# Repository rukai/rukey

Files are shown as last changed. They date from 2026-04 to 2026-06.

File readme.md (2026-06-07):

# Rukey



## About

This was designed quickly as my personal keyboard, I would like to make this a properly documented project that others can build but don't have the capacity at the moment.

I used the sofle pico as a base but changed pretty much everything in order to recreate the moonlander but with the goal of being a budget build.

## BOM

[Printed parts onshape](https://cad.onshape.com/documents/f6585266405bfc96ac0755a6/w/eb9972e583e4bd12c4cf19cb/e/e24845aae63ec51d7ef00fa9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)

|Quantity|Item|Note|
|-|-|-|
|74| MX compatible switches| |
|74| MX compatible kailh hotswap sockets| |
|74| Surface mount SOD-123 1N4148 diodes| |
|2| 2x08 2.00mm IDC straight socket| |
|1| 2x08 2.00mm IDC cable - at least 20cm long| |
|4| 2x03 2.00mm pin header |used as IDC socket in tight area |
|2| 2x03 2.00mm IDC cable - ~10cm long | |
|1| printed left base|print with supports for the bridge, can be done with auto supports configured to 1 degree|
|1| printed right base| same as above|
|1| printed switch plate - left main|no supports|
|1| printed switch plate - right main|no supports|
|1| printed switch plate - left thumb cluster|no supports|
|1| printed switch plate - right thumb cluster|no supports|
|2| printed washers|no supports|
|4| m3 machine screws - 25mm long||
|2| m3 machine screws - 20mm long||
|2| m3 machine screws - 14mm long||
|2| m3 machine screws - 12mm long||
|10| m3 square nuts| |
|2|main PCB| |
|2|thumb cluster PCB| |

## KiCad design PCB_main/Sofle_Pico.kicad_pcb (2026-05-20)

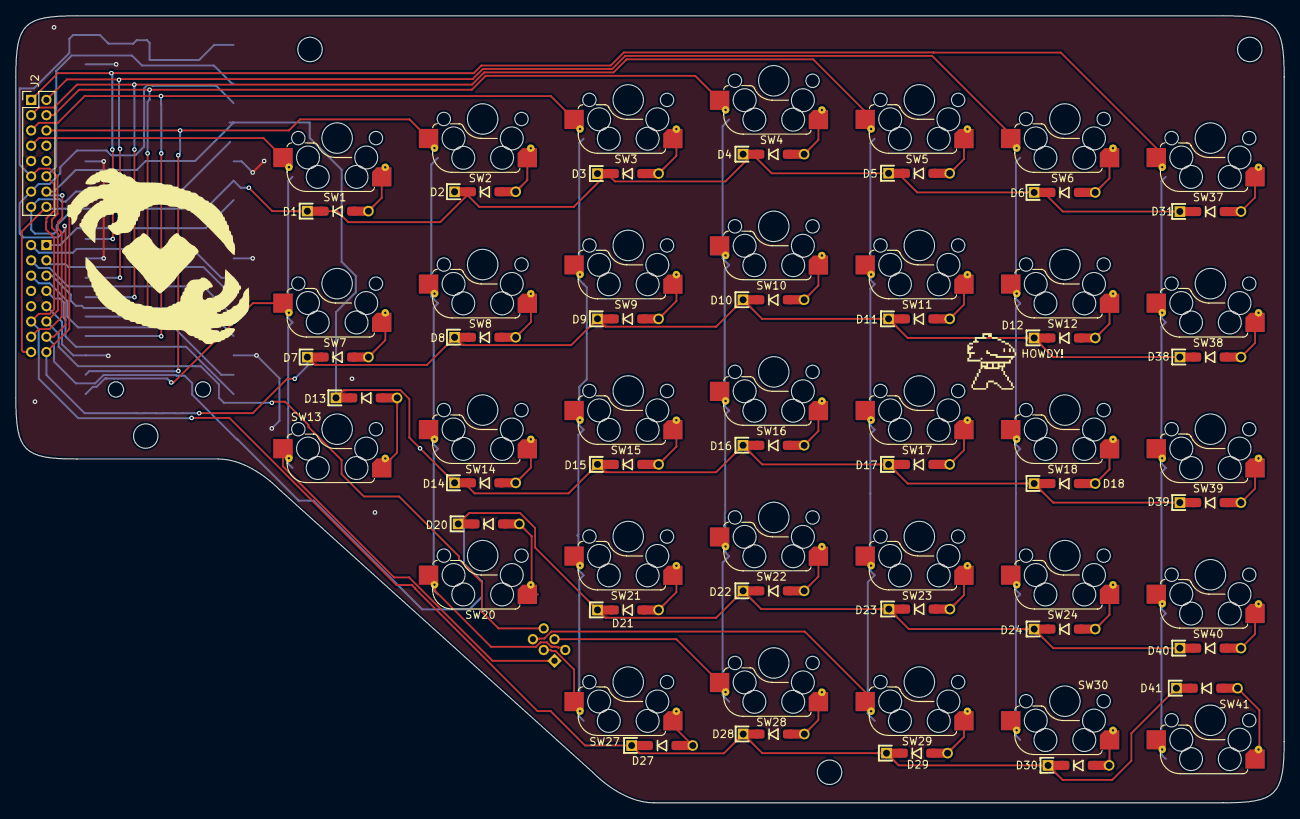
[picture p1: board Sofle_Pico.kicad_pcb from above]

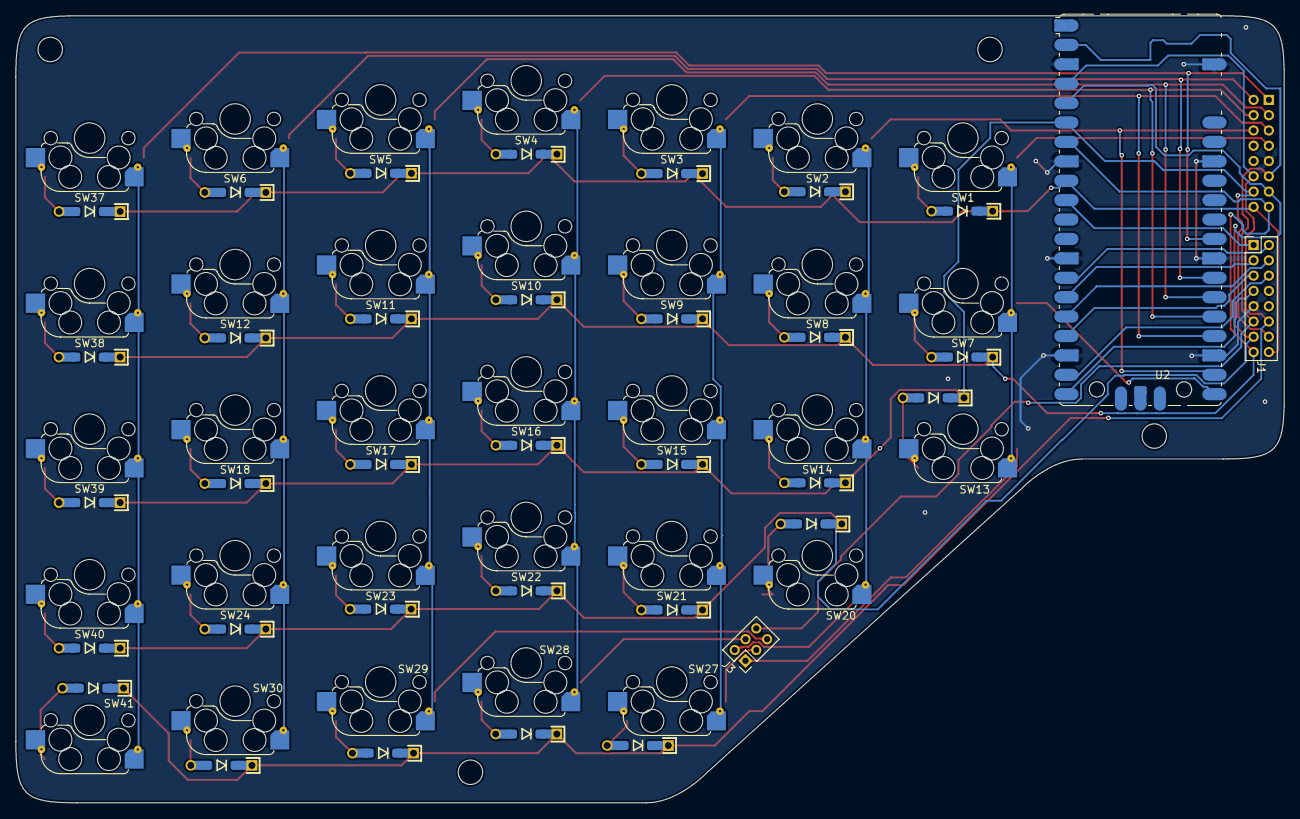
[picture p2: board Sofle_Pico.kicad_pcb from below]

Board: 2 copper layers, 166.0 x 103.0 mm, 68 parts (67 on the bottom side), 53 nets.

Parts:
D1, D2, D3, D4, D5, D6, D7, D8, D9, D10, D11, D12, D13, D14, D15, D16, D17, D18, D20, D21, D22, D23, D24, D27, D28, D29, D30, D31, D38, D39, D40, D41: D; D_SOD-123_DO-35_Hybrid_DoubleSided_V2
J1, J2: Conn_02x08_Top_Bottom; PinHeader_2x08_P2.00mm_Vertical
J3: Conn_02x03; PinHeader_2x03_P2.00mm_Vertical
SW1, SW2, SW3, SW4, SW5, SW6, SW7, SW8, SW9, SW10, SW11, SW12, SW13, SW14, SW15, SW16, SW17, SW18, SW20, SW21, SW22, SW23, SW24, SW27, SW28, SW29, SW30, SW37, SW38, SW39, SW40, SW41: SW_PUSH; Cherry_MX_DS_Hotswap_v3.5.4
U2: Pico; RaspberryPi_Pico_SMD

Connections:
GND: J1.9, J2.9, U2.3 (GND), U2.8 (GND), U2.13 (GND), U2.18 (GND), U2.23 (GND), U2.28 (GND), U2.33 (AGND), U2.38 (GND)
unnamed: D1.2 (A), SW1.2
unnamed: D2.2 (A), SW2.2
unnamed: D3.2 (A), SW3.2
unnamed: D4.2 (A), SW4.2
unnamed: D5.2 (A), SW5.2
unnamed: D6.2 (A), SW6.2
unnamed: D7.2 (A), SW7.2
unnamed: D8.2 (A), SW8.2
unnamed: D9.2 (A), SW9.2
unnamed: D10.2 (A), SW10.2
unnamed: D11.2 (A), SW11.2
unnamed: D12.2 (A), SW12.2
unnamed: D13.2 (A), SW13.2
unnamed: D14.2 (A), SW14.2
unnamed: D15.2 (A), SW15.2
unnamed: D16.2 (A), SW16.2
unnamed: D17.2 (A), SW17.2
unnamed: D18.2 (A), SW18.2
unnamed: D20.2 (A), SW20.2
unnamed: D21.2 (A), SW21.2
unnamed: D22.2 (A), SW22.2
unnamed: D23.2 (A), SW23.2
unnamed: D24.2 (A), SW24.2
unnamed: D27.2 (A), SW27.2
unnamed: D28.2 (A), SW28.2
unnamed: D29.2 (A), SW29.2
unnamed: D30.2 (A), SW30.2
unnamed: D31.2 (A), SW37.2
unnamed: D38.2 (A), SW38.2
unnamed: D39.2 (A), SW39.2
unnamed: D40.2 (A), SW40.2
unnamed: D41.2 (A), SW41.2
lcol0: J2.7, J3.1, SW1.1, SW7.1, SW13.1, U2.21 (GPIO16)
lcol1: J2.6, J3.2, SW2.1, SW8.1, SW14.1, SW20.1, U2.22 (GPIO17)
lcol2: J2.5, J3.3, SW3.1, SW9.1, SW15.1, SW21.1, SW27.1, U2.24 (GPIO18)
lcol3: J2.4, J3.4, SW4.1, SW10.1, SW16.1, SW22.1, SW28.1, U2.25 (GPIO19)
lcol4: J2.3, J3.5, SW5.1, SW11.1, SW17.1, SW23.1, SW29.1, U2.26 (GPIO20)
lcol5: J2.2, SW6.1, SW12.1, SW18.1, SW24.1, SW30.1, U2.27 (GPIO21)
lcol6: J2.1, SW37.1, SW38.1, SW39.1, SW40.1, SW41.1, U2.29 (GPIO22)
rcol0: J1.7, U2.20 (GPIO15)
rcol1: J1.6, U2.19 (GPIO14)
rcol2: J1.5, U2.17 (GPIO13)
rcol3: J1.4, U2.16 (GPIO12)
rcol4: J1.3, U2.15 (GPIO11)
rcol5: J1.2, U2.14 (GPIO10)
rcol6: J1.1, U2.10 (GPIO7)
row0: D1.1 (K), D2.1 (K), D3.1 (K), D4.1 (K), D5.1 (K), D6.1 (K), D31.1 (K), J1.16, J2.16, U2.9 (GPIO6)
row1: D7.1 (K), D8.1 (K), D9.1 (K), D10.1 (K), D11.1 (K), D12.1 (K), D38.1 (K), J1.15, J2.15, U2.7 (GPIO5)
row2: D13.1 (K), D14.1 (K), D15.1 (K), D16.1 (K), D17.1 (K), D18.1 (K), D39.1 (K), J1.14, J2.14, U2.6 (GPIO4)
row3: D20.1 (K), D21.1 (K), D22.1 (K), D23.1 (K), D24.1 (K), D40.1 (K), J1.13, J2.13, U2.5 (GPIO3)
row4: D27.1 (K), D28.1 (K), D29.1 (K), D30.1 (K), D41.1 (K), J1.12, J2.12, U2.4 (GPIO2)
row5: J1.11, J2.11, J3.6, U2.2 (GPIO1)

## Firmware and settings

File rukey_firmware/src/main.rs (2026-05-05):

#![no_main]
#![no_std]

//! Stack usage.
//! The rukey firmware does not use an allocator.
//! Maybe it should, but its interesting to try writing software without an allocator,
//! and assuming we are well under the memory limit, using static buffers should make OoM issues impossible.
//!
//! However, currently rukey stores huge values on the stack, which is problematic because:
//! * The RP2040 only has 256KB of RAM
//! * embassy/async exacerbates stack usage issues
//!
//! memory.x is setup to assert that the linker has allocated at least 64KB of stack.
//! Currently, the firmware works fine, but long term we should move anything >= 1024 bytes off of the stack to avoid stack overflow issues.

mod config;
mod input;
mod keyboard;
mod mapping_state;
mod mouse;
mod usb;
mod web_config;

use crate::config::ConfigFlash;
use crate::input::Inputs;
use crate::keyboard::Keyboard;
use crate::mouse::Mouse;
use crate::web_config::WebConfig;
use embassy_executor::Spawner;

use {defmt_rtt as _, panic_probe as _};

#[embassy_executor::main]
async fn main(_spawner: Spawner) {
    let p = embassy_rp::init(Default::default());

    let config_flash = ConfigFlash::new(p.FLASH, p.DMA_CH0).await;

    let mut builder = usb::usb_builder(p.USB, config_flash).await;

    let mut web_config = WebConfig::new(&mut builder, config_flash);

    let mut keyboard = Keyboard::new(&mut builder);
    let mut mouse = Mouse::new(&mut builder);

    let mut usb = builder.build();

    // Run the USB device.
    let usb_fut = usb.run();

    let mut inputs = Inputs::new(
        config_flash,
        [
            Some(p.PIN_0.into()),
            Some(p.PIN_1.into()),
            Some(p.PIN_2.into()),
            Some(p.PIN_3.into()),
            Some(p.PIN_4.into()),
            Some(p.PIN_5.into()),
            Some(p.PIN_6.into()),
            Some(p.PIN_7.into()),
            Some(p.PIN_8.into()),
            Some(p.PIN_9.into()),
            Some(p.PIN_10.into()),
            Some(p.PIN_11.into()),
            Some(p.PIN_12.into()),
            Some(p.PIN_13.into()),
            Some(p.PIN_14.into()),
            Some(p.PIN_15.into()),
            Some(p.PIN_16.into()),
            Some(p.PIN_17.into()),
            Some(p.PIN_18.into()),
            Some(p.PIN_19.into()),
            Some(p.PIN_20.into()),
            Some(p.PIN_21.into()),
            Some(p.PIN_22.into()),
            Some(p.PIN_23.into()),
            Some(p.PIN_24.into()),
            Some(p.PIN_25.into()),
            Some(p.PIN_26.into()),
            Some(p.PIN_27.into()),
            Some(p.PIN_28.into()),
            Some(p.PIN_29.into()),
        ],
    );

    embassy_futures::join::join5(
        usb_fut,
        inputs.process(),
        keyboard.process(),
        mouse.process(),
        web_config.process(),
    )
    .await;
}

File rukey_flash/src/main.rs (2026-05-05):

use crate::flash::WriteConfig;
use clap::Parser;
use miette::Result;

pub mod buffer_nor_flash;
pub mod cli;
pub mod config;
pub mod elf;
pub mod flash;

fn main() -> Result<()> {
    // TODO: use this once -Z bindeps stabilizes
    // let firmware_bytes = elf::elf_to_bin(include_bytes!(env!(
    //     "CARGO_BIN_FILE_rukey_FIRMWARE_rukey_firmware"
    // )))?;
    let firmware_bytes = elf::elf_to_bin(include_bytes!(env!("FIRMWARE_PATH")))?;

    let cli = cli::Args::parse();
    let config = if cli.erase_config {
        WriteConfig::Clear
    } else {
        WriteConfig::Config(Box::new(config::load(cli.path)?))
    };
    flash::flash_device(&firmware_bytes, config)?;

    println!("Succesfully flashed!");
    Ok(())
}

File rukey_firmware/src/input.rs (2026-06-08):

use crate::config::{CONFIG_UPDATED, ConfigFlash};
use crate::mapping_state::MappingState;
use core::ops::ControlFlow;
use defmt::info;
use embassy_rp::gpio::{AnyPin, Input, Output, Pin, Pull};
use embassy_rp::{Peri, PeripheralType};
use embassy_sync::{blocking_mutex::raw::CriticalSectionRawMutex, mutex::Mutex};
use embassy_time::Timer;
use heapless::Vec;
use rukey_config::{MAX_MAPPINGS, Profile, RukeyInput};
use static_cell::StaticCell;

static CURRENT_PROFILE: StaticCell<Profile> = StaticCell::new();

pub struct Inputs {
    pins: [Option<Peri<'static, AnyPin>>; 30],
    config_flash: &'static Mutex<CriticalSectionRawMutex, ConfigFlash>,
}

impl Inputs {
    pub fn new(
        config_flash: &'static Mutex<CriticalSectionRawMutex, ConfigFlash>,
        pins: [Option<Peri<'static, AnyPin>>; 30],
    ) -> Self {
        Inputs { pins, config_flash }
    }

    pub async fn process(&mut self) {
        let mut rx = CONFIG_UPDATED.receiver().unwrap();

        // lcol pins 0-6
        // lcol pins are mirrored from rcol pins, so the two innermost columns are 0 and the outermost columns are 6.
        // However, to make mapping configuration feel more natural, we convert these mirrored pins into a series of columns from 0-13 going from left to right
        // i.e. 6543210 0123456
        let col0_pin = 22; // lcol 6
        let col1_pin = 21; // lcol 5
        let col2_pin = 20; // lcol 4
        let col3_pin = 19; // lcol 3
        let col4_pin = 18; // lcol 2
        let col5_pin = 17; // lcol 1
        let col6_pin = 16; // lcol 0

        // rcol pins 0-6
        let col7_pin = 15; // rcol 0
        let col8_pin = 14; // rcol 1
        let col9_pin = 13; // rcol 2
        let col10_pin = 12; // rcol 3
        let col11_pin = 11; // rcol 4
        let col12_pin = 10; // rcol 5
        let col13_pin = 7; // rcol 6

        let row0_pin = 6;
        let row1_pin = 5;
        let row2_pin = 4;
        let row3_pin = 3;
        let row4_pin = 2;
        let row5_pin = 1;

        // Load initial config
        let _meta = self.config_flash.lock().await.load_meta().await; // TODO: pin remappings
        let current_profile = {
            // TODO: currently handles config with 0 profiles by loading the default profile which has mappings in it.
            //       this is unintuitive and should be changed.
            let profile = self.config_flash.lock().await.load_profile(0).await;
            CURRENT_PROFILE.init(profile)
        };

        let mut cols = [
            output(self.pins[col0_pin].take().unwrap()),
            output(self.pins[col1_pin].take().unwrap()),
            output(self.pins[col2_pin].take().unwrap()),
            output(self.pins[col3_pin].take().unwrap()),
            output(self.pins[col4_pin].take().unwrap()),
            output(self.pins[col5_pin].take().unwrap()),
            output(self.pins[col6_pin].take().unwrap()),
            output(self.pins[col7_pin].take().unwrap()),
            output(self.pins[col8_pin].take().unwrap()),
            output(self.pins[col9_pin].take().unwrap()),
            output(self.pins[col10_pin].take().unwrap()),
            output(self.pins[col11_pin].take().unwrap()),
            output(self.pins[col12_pin].take().unwrap()),
            output(self.pins[col13_pin].take().unwrap()),
        ];
        let rows = [
            input(self.pins[row0_pin].take().unwrap()),
            input(self.pins[row1_pin].take().unwrap()),
            input(self.pins[row2_pin].take().unwrap()),
            input(self.pins[row3_pin].take().unwrap()),
            input(self.pins[row4_pin].take().unwrap()),
            input(self.pins[row5_pin].take().unwrap()),
        ];

        let mut state = State::new();
        let mut loaded_profile_index: u8 = 0;

        static INPUT_STATE: StaticCell<RukeyInputState> = StaticCell::new();
        let input_state = INPUT_STATE.init(RukeyInputState::new());

        'main_loop: loop {
            // Detect config updates (ReloadConfig from web configurator); reset to profile 0
            if rx.try_changed().is_some() {
                state = State::new();
                loaded_profile_index = u8::MAX; // force reload via the block below
            }

            // Load new profile from flash when current profile changed
            if state.current_profile != loaded_profile_index {
                *current_profile = self
                    .config_flash
                    .lock()
                    .await
                    .load_profile(state.current_profile)
                    .await;
                loaded_profile_index = state.current_profile;
                state.mapping_states.clear();
            }

            input_state.update(&rows, &mut cols).await;

            // Restore mapping state to full length in case it was cleared earlier
            while current_profile.mappings.len() > state.mapping_states.len() {
                if state.mapping_states.push(MappingState::new()).is_err() {
                    defmt::panic!("mapping state overflow");
                }
            }

            let mut all_pressed_arr: [bool; MAX_MAPPINGS] = [false; MAX_MAPPINGS];
            for (mapping, e) in current_profile
                .mappings
                .iter()
                .zip(all_pressed_arr.iter_mut())
            {
                *e = input_state.is_all_pressed(&mapping.input_set);
            }

            for (i, mapping) in current_profile.mappings.iter().enumerate() {
                let suppressed = all_pressed_arr[i]
                    && current_profile
                        .mappings
                        .iter()
                        .enumerate()
                        .any(|(j, other)| {
                            j != i
                                && all_pressed_arr[j]
                                && other.input_set.len() > mapping.input_set.len()
                                && mapping
                                    .input_set
                                    .iter()
                                    .all(|k| other.input_set.contains(k))
                        });
                state.mapping_states[i] = match state.mapping_states[i]
                    .process(mapping, all_pressed_arr[i], suppressed, &mut state)
                    .await
                {
                    ControlFlow::Continue(ms) => ms,
                    ControlFlow::Break(()) => continue 'main_loop,
                };
            }

            Timer::after_millis(1).await;
        }
    }
}

pub(crate) struct State {
    /// The index of the currently selected profile
    pub(crate) current_profile: u8,
    /// Tracks press/release state for each mapping in the current profile
    pub(crate) mapping_states: Vec<MappingState, MAX_MAPPINGS>,
}

impl State {
    fn new() -> Self {
        State {
            current_profile: 0,
            mapping_states: Vec::new(),
        }
    }
}
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

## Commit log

2026-04-09 second board is not smart
    [Sofle_Pico.kicad_pcb, Sofle_Pico.kicad_sch]
2026-04-11 chop off unneeded keys
    [Sofle_Pico.kicad_pcb, Sofle_Pico.kicad_sch]
2026-04-11 add thumb cluster board
    [Sofle_Pico.dsn, Sofle_Pico.kicad_pcb, Sofle_Pico.kicad_sch]
2026-04-11 improve positioning
    [Sofle_Pico.kicad_pcb, Sofle_Pico.kicad_sch]
2026-04-25 more pcb progress
    [Sofle_Pico.kicad_pcb, Sofle_Pico.kicad_sch]
2026-04-25 rotate idc socket
    [Sofle_Pico.kicad_pcb, Sofle_Pico.kicad_sch]
2026-04-25 route thumb cluster
    [Sofle_Pico.kicad_pcb, Sofle_Pico.kicad_sch]
2026-04-26 adjust holes
    [Sofle_Pico.kicad_pcb, Sofle_Pico.kicad_sch]
2026-04-26 more pcb
    [Sofle_Pico.kicad_pcb]
2026-04-26 relayout thumbcluster
    [Sofle_Pico.kicad_pcb, Sofle_Pico.kicad_sch]
2026-04-27 thumb cluster connection uses idc
    [Sofle_Pico.kicad_pcb, Sofle_Pico.kicad_sch]
2026-05-09 fix pcb
    [Sofle_Pico.kicad_pcb, Sofle_Pico.kicad_sch]
2026-05-09 more pcb work
    [Sofle_Pico.kicad_pcb, Sofle_Pico.kicad_sch]
2026-05-16 improve pin mapping
2026-05-20 remove pico testpads from pcb
    [Sofle_Pico.kicad_pcb]
2026-06-06 bom fix
